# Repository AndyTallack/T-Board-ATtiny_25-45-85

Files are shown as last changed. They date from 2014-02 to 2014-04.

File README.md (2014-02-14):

T-Board-Atiny 25/45/85
======================

T-Board for use on Breadboard - Attiny 25/45/85

This is a series of boards to speed up development of your own standalone ATMega/ATTiny projects.  The T-Board houses the microprocessor, power-supply and FTDI interface, with a breadboard-compatible footprint.  This allows you to get up and running fast with the core ATMega/ATTiny "heart" of your project.

This board is based on the great Arduino concept, and is compatible with the Arduino IDE.  It differs in that it:
- allows you to switch between 3.3V and 5V
- allows you to select crystals for low-power applications
- fits snugly into a breadboard, keeping your project together

There are 2 sets of schematic:
- T-Board-45-85 Etch:	1-layer, for hand-etching.  No ICSP header
- T-Board-45-85 PCB:	2-layer, for production-house.  With ICSP header

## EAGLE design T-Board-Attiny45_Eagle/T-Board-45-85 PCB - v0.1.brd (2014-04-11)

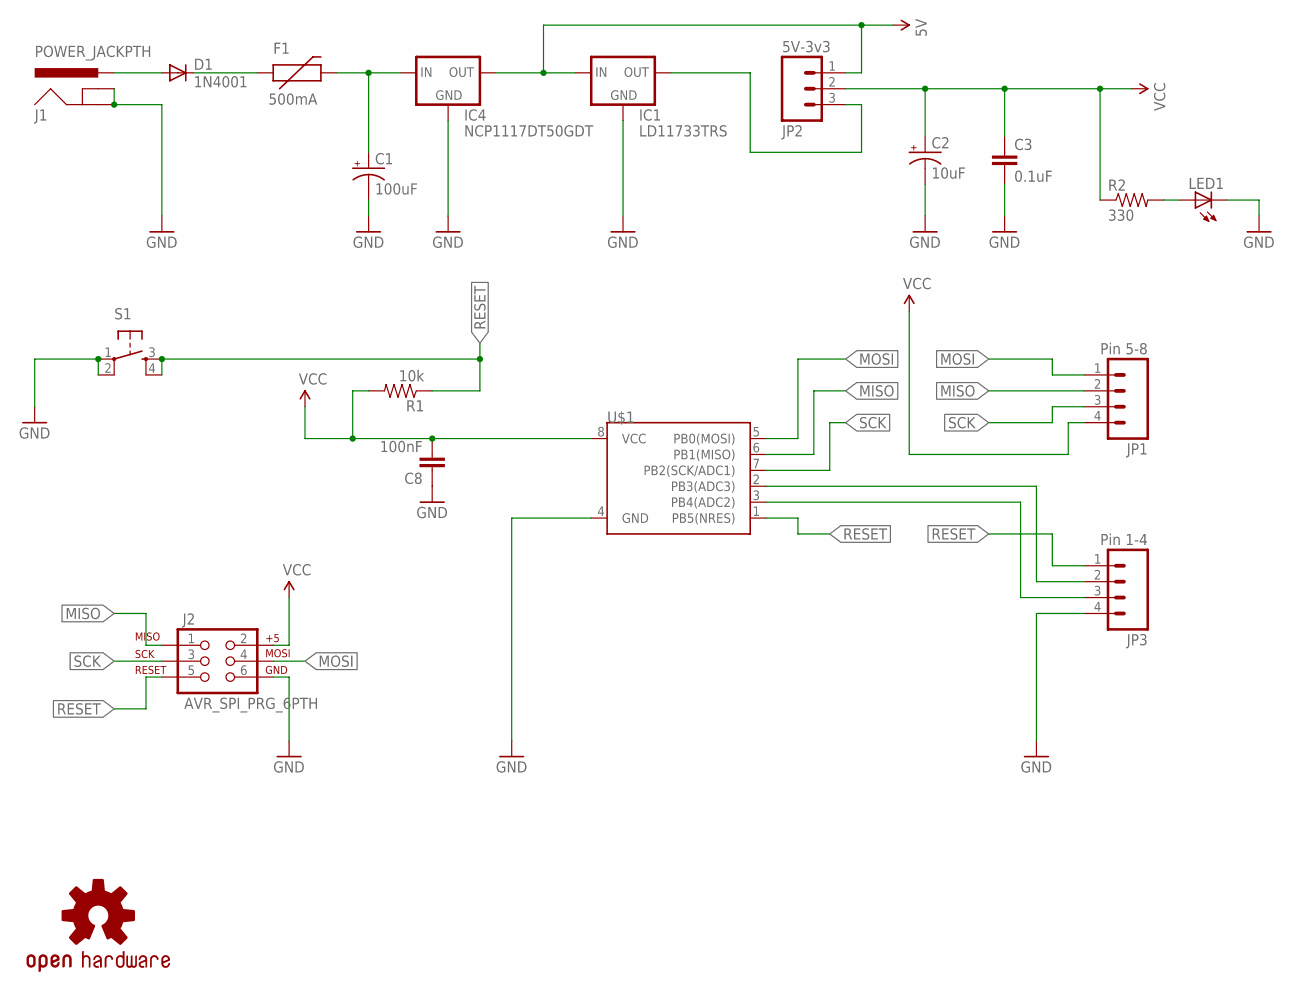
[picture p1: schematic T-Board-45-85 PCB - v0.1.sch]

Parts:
C1: 100uF; CPOL-RADIAL-100UF-25V
C2: 10uF; CPOL-RADIAL-10UF-25V
C3: 0.1uF; 1206
C8: 100nF; 1206
D1: 1N4001; DIODE-1N4001
F1: 500mA; PTC
IC1: LD11733TRS; SOT223
IC4: NCP1117DT50GDT; DPACK
J1: POWER_JACKPTH; POWER_JACK_PTH
J2: AVR_SPI_PRG_6PTH; 2X3
JP1: Pin 5-8; 1X04
JP2: 5V-3v3; 1X03
JP3: Pin 1-4; 1X04
LED1: LED1206; LED-1206
LOGO1: OSHW-LOGOS; OSHW-LOGO-S
R1: 10k; 1206
R2: 330; 1206
S1: TAC_SWITCHPTH; TACTILE-PTH
U$1: ATTINY45TINY45-20-DIP; DIP08

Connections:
5V: IC1.3 (IN), IC4.4 (OUT), JP2.1
GND: C1.2 (-), C2.2 (-), C3.2, C8.1, IC1.1 (GND), IC4.1 (GND), J1.GND, J1.GNDBREAK, J2.6, JP3.4, LED1.C, S1.1, S1.2, U$1.4 (GND)
MISO: J2.1, JP1.2, U$1.6 (PB1(MISO))
MOSI: J2.4, JP1.1, U$1.5 (PB0(MOSI))
unnamed: D1.A, J1.PWR
unnamed: D1.C, F1.P$1 (1)
unnamed: C1.1 (+), F1.P$2 (2), IC4.3 (IN)
unnamed: JP3.2, U$1.2 (PB3(ADC3))
unnamed: JP3.3, U$1.3 (PB4(ADC2))
unnamed: LED1.A, R2.2
unnamed: IC1.4 (OUT), JP2.3
RESET: J2.5, JP3.1, R1.1, S1.3, S1.4, U$1.1 (PB5(NRES))
SCK: J2.3, JP1.3, U$1.7 (PB2(SCK/ADC1))
VCC: C2.1 (+), C3.1, C8.2, J2.2, JP1.4, JP2.2, R1.2, R2.1, U$1.8 (VCC)

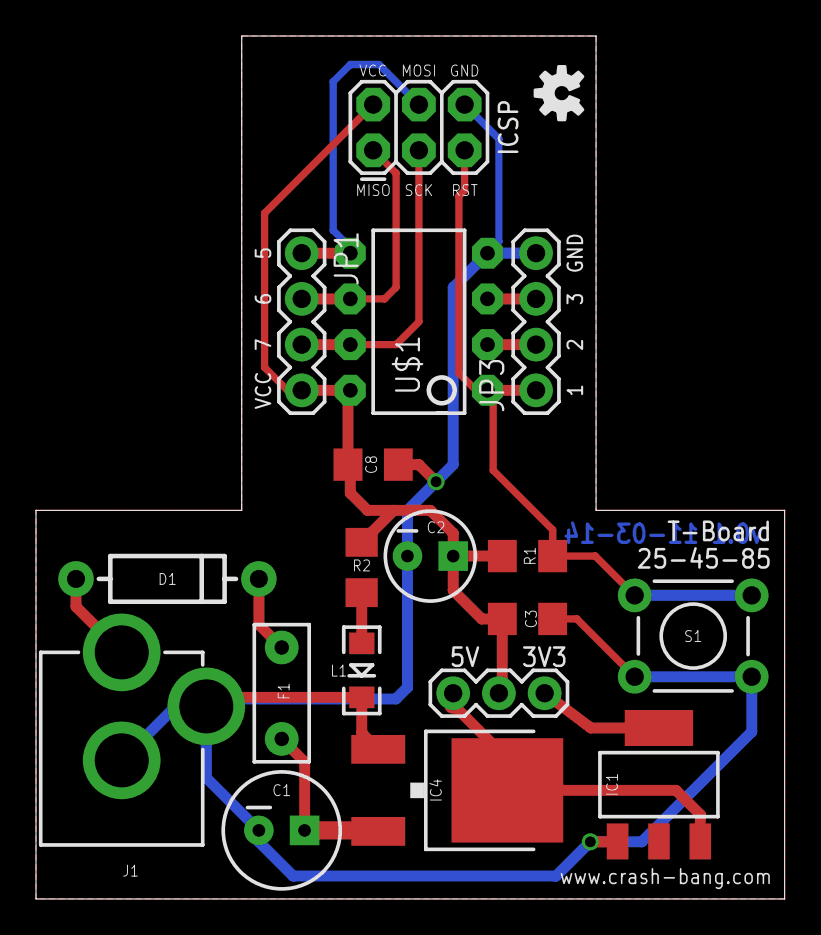
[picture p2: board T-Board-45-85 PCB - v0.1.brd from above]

Board: 2 copper layers, 41.6 x 47.9 mm, 19 parts (0 on the bottom side), 14 nets.

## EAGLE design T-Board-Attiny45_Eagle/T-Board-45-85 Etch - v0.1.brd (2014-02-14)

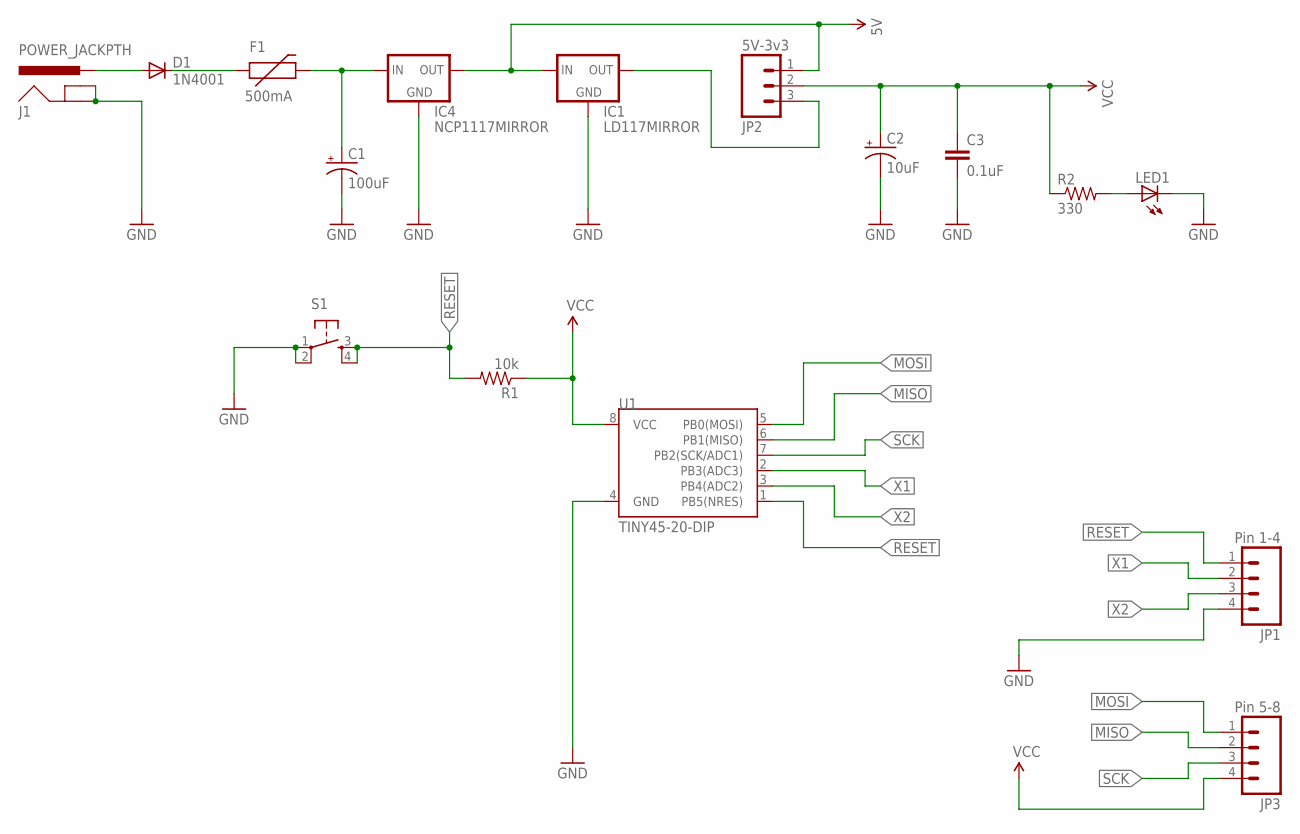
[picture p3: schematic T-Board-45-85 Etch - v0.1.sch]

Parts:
C1: 100uF; CPOL-RADIAL-100UF-25V
C2: 10uF; CPOL-RADIAL-10UF-25V
C3: 0.1uF; 1206
D1: 1N4001; DIODE-1N4001
F1: 500mA; PTC
IC1: LD117MIRROR; SOT223
IC4: NCP1117MIRROR; DPACK
J1: POWER_JACKPTH; POWER_JACK_PTH
JP1: Pin 1-4; 1X04
JP2: 5V-3v3; 1X03
JP3: Pin 5-8; 1X04
LED1: LED1206; LED-1206
R1: 10k; 1206
R2: 330; 1206
S1: TAC_SWITCHPTH; TACTILE-PTH
U1: TINY45-20-DIP; DIP08

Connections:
5V: IC1.1 (IN), IC4.4 (OUT), JP2.1
GND: C1.2 (-), C2.2 (-), C3.2, IC1.3 (GND), IC4.3 (GND), J1.GND, J1.GNDBREAK, JP1.4, LED1.C, S1.1, S1.2, U1.4 (GND)
MISO: JP3.2, U1.6 (PB1(MISO))
MOSI: JP3.1, U1.5 (PB0(MOSI))
unnamed: D1.A, J1.PWR
unnamed: D1.C, F1.P$1 (1)
unnamed: C1.1 (+), F1.P$2 (2), IC4.1 (IN)
unnamed: LED1.A, R2.2
unnamed: IC1.4 (OUT), JP2.3
RESET: JP1.1, R1.2, S1.3, S1.4, U1.1 (PB5(NRES))
SCK: JP3.3, U1.7 (PB2(SCK/ADC1))
VCC: C2.1 (+), C3.1, JP2.2, JP3.4, R1.1, R2.1, U1.8 (VCC)
X1: JP1.2, U1.2 (PB3(ADC3))
X2: JP1.3, U1.3 (PB4(ADC2))

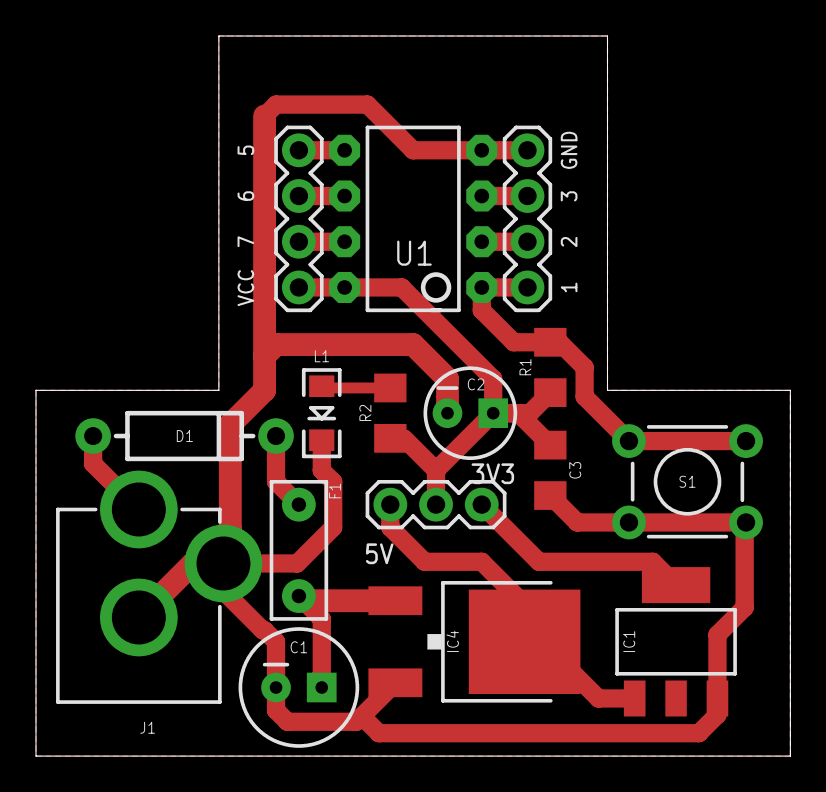
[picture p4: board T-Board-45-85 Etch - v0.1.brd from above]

Board: 2 copper layers, 41.9 x 40.0 mm, 16 parts (0 on the bottom side), 14 nets.

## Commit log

2014-02-14 v0.1 - Initial Prototype
    Untested prototype
    [T-Board-45-85 Etch - v0.1.brd, T-Board-45-85 Etch - v0.1.sch, T-Board-45-85 PCB - v0.1.brd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]
2014-03-16 v0.2 - 2-sided prototype
    2-sided prototype send to OSHPark to fab. Includes:
    - ICSP header
    - Consistency in trace width
    [T-Board-45-85 PCB - v0.1.brd, T-Board-45-85 PCB - v0.1.sch]
2014-04-11 Adjusted header pins
    Header pins spacing corrected to fit breadboard more precisely
    [T-Board-45-85 PCB - v0.1.brd]

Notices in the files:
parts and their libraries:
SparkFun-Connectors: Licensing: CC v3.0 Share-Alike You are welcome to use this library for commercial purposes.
